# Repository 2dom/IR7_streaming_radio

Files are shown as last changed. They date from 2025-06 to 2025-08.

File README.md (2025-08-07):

<p style="color: #87CEEB"> DISCLAIMER: THE DESIGN FILES IN THIS REPOSITORY HAVE BEEN CLEARED OF ANY TRADEMARK-PROTECTED LOGOS.</p>

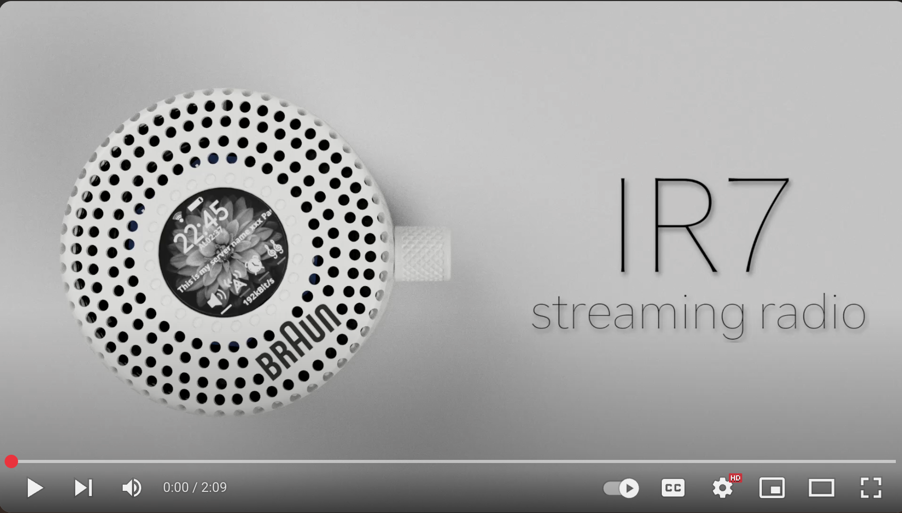
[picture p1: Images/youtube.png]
<p align="center"></p>

<h1>Less, but better</h1>
Legendary German industrial designer Dieter Rams is best known for his tenure at Braun, where he developed a design philosophy that emphasized simplicity, functionality, and clarity. His work was guided by the principle "Less, but better" (“Weniger, aber besser”), aiming to strip objects down to their essential purpose without unnecessary embellishment. Rams believed that good design is as little design as possible, and this ethos permeated his creations at Braun. His iconic "Ten Principles of Good Design" laid a foundation not only for Braun's product identity but also for the evolution of modern design aesthetics in consumer electronics globally.<br>
<br><br>
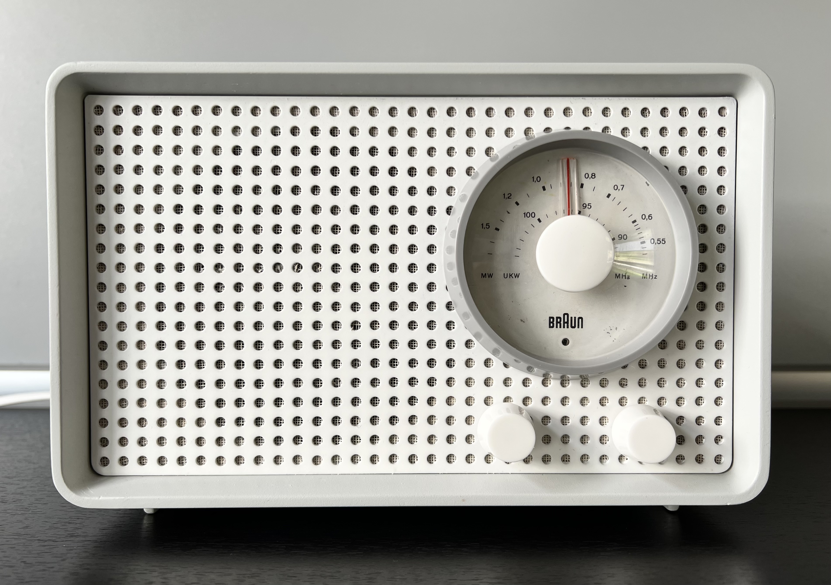
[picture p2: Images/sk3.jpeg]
<p align="center"><br>
Braun SK2 radio</p><br>
Among Rams' most influential designs are the SK2 radio, the TP1, and the T3 Pocket Radio. The SK2, introduced in 1955, featured a minimal white casing with a clear, intuitive layout, embodying the clarity and honesty Rams championed. The TP1 combined a record player and radio into one compact, portable device—a groundbreaking integration at the time—highlighting Rams’ commitment to multifunctional utility and user-friendly design. The T3 Pocket Radio, released in 1958, took these values even further: it was compact, elegant, and remarkably prescient, widely regarded as a spiritual predecessor to the Apple iPod due to its minimalist front face and clear functional layout.<br>
<br>
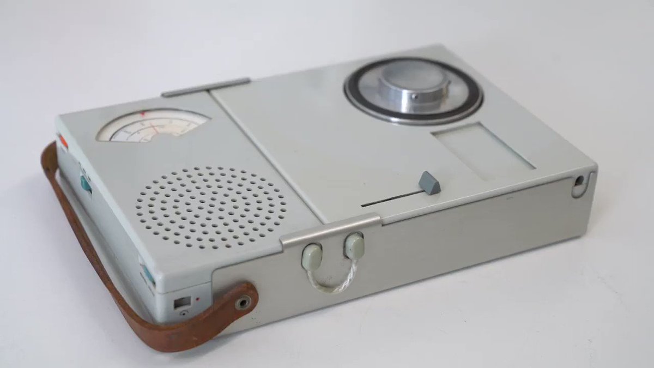
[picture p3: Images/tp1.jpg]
<p align="center"><br>
Braun TP1 portable record player</p><br>
Rams' influence on the design industry, particularly on companies like Apple, is unmistakable. Jony Ive, Apple’s former chief design officer, openly credited Rams as a major inspiration for the look and feel of Apple products. The restrained elegance and user-centric functionality of Braun devices under Rams’ direction clearly echo in Apple’s hardware—from the clean lines of the iPhone to the intuitive control layout of the iPod. Through designs like the SK2, TP1, and T3, Rams didn't just shape Braun’s identity; he helped define what good design means in the modern world, leaving a legacy that continues to shape the aesthetics and usability of consumer technology today.<br>
<br>
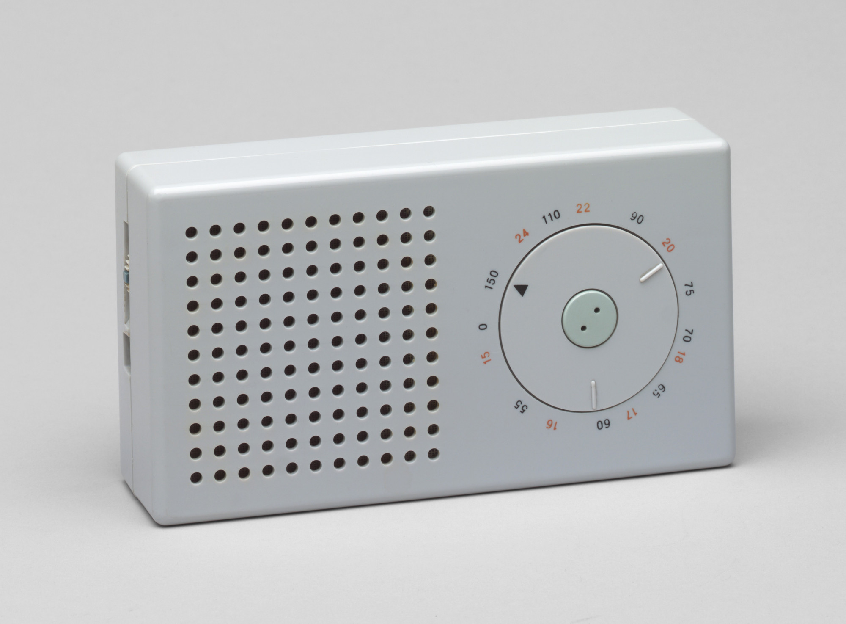
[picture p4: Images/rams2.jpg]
<p align="center"><br>
 Braun T3 portable radio</p>
<br>
After a glorious period of minimalist designwork, Dieter Rams' left Braun in the mid-1990s and the company gradually shifted away from its legacy of minimalist consumer electronics toward high quality personal care products, such as electric shavers, hair dryers, and epilators. <br>
<br>
Dieter Rams' design legacy lives on in many contemporary products, such as the portable recorders and synthesizers by Teenage Engineering.<br><br>
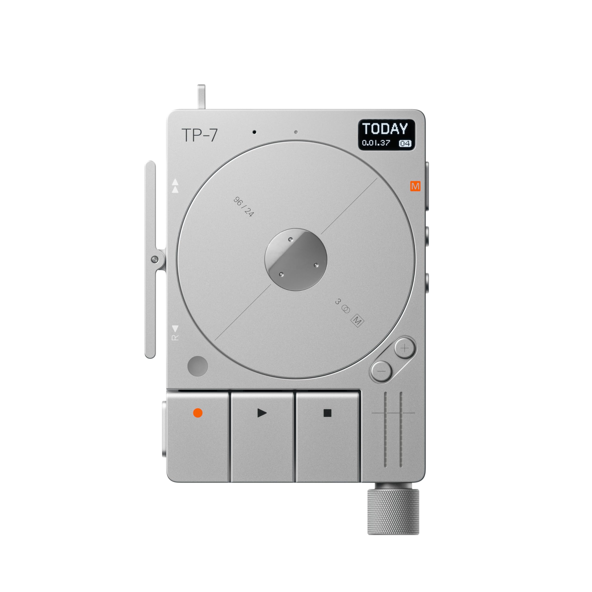
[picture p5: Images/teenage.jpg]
<p align="center"><br>
Teenage Engineering TP-7</p>

<h1>Something new</h1>
<p>Inspired by Braun’s iconic designs, particularly the T3, I started from the familiar speaker hole pattern and gradualy added elements that worked visually and physically (would fit the electronics). The first attempt was a direct copy of the T3 with an added square display (much like the iPod). Albeit the design worked reasonably well, it also felt overused and a lost opportunity in creating something new.<br>
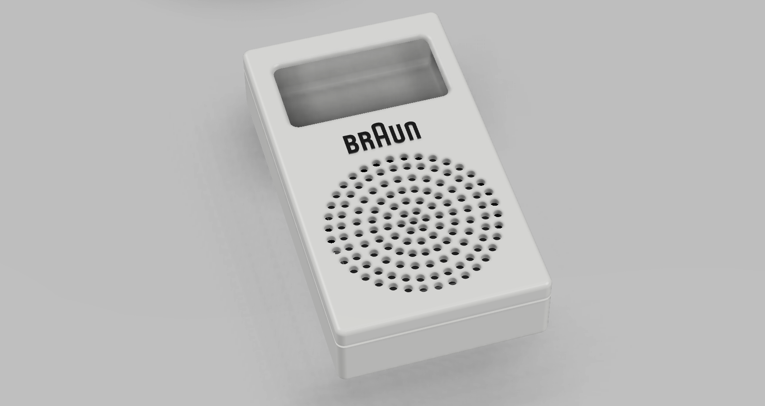
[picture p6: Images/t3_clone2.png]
 <p align="center"><br>
First concept based on T3 shape and TP1 hole pattern</p>
I kept experimenting with different shapes until a cylindrical form emerged, driven by the original hole pattern and the dimensions of the speaker. The top section simply extends the pattern into the 3rd dimensions, effectively serving as a 360 degree speaker grill. To complete the design, I also added the distinctive top/bottom gap reminiscent of the classic T3 that ties everything together.</p>
<p>Initially, I opted for a rectangular ultra–low-power monochrome display to maximize battery life. However, I soon realized that a) it looks rather hacked together b) such displays lack backlighting, making them practically unusable in an alarm clock / low-light kind of situation. So might as well use nice a round IPS LCD and turn it off during sleep. Not only does it complement the circular design of the case far more naturally, but it also offers a significantly better user experience thanks to its higher resolution and contrast.</p>
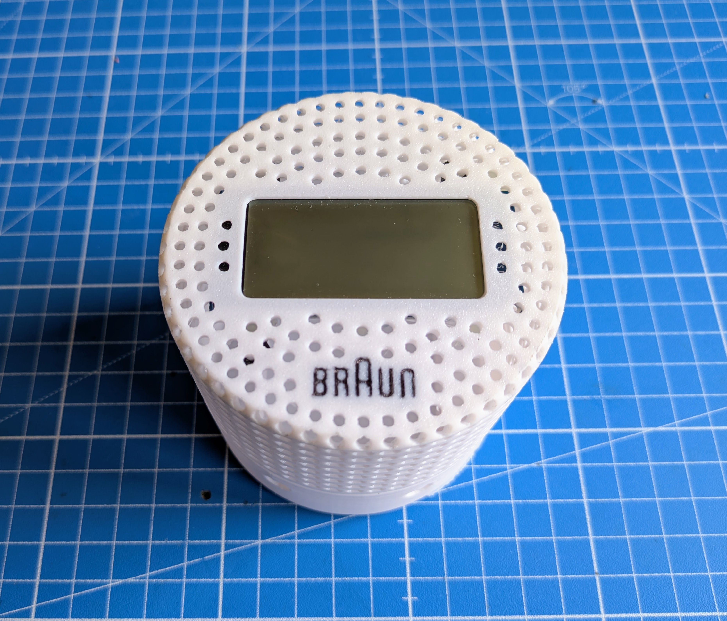
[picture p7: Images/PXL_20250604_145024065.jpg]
<p align="center"><br>
Rectangular ultra-low-power display</p>
<p>So how do we operate this thing? Although the GC9A01 also comes in a "touch" variant, I decided that a physical interface would work better for this build. I started off with two encoder knobs (one for station, one for volume), but reduced it later to a single knob angled at 45-degrees. This choice aligned much better with rest of the design and effectively simplified the user interface.<br>
 <br>Battery life is reasonably good too. The radio has a current consumption of about 800uA during sleep and 200mA during radio operation which equates to 220 days of standy or 22h of radio play using two 2200mAh 18650 cells. If you use it as a alarm clock, that's about 1.5 months of battery life, given that you need 30min to get out of bed each morning.</p>
<br>
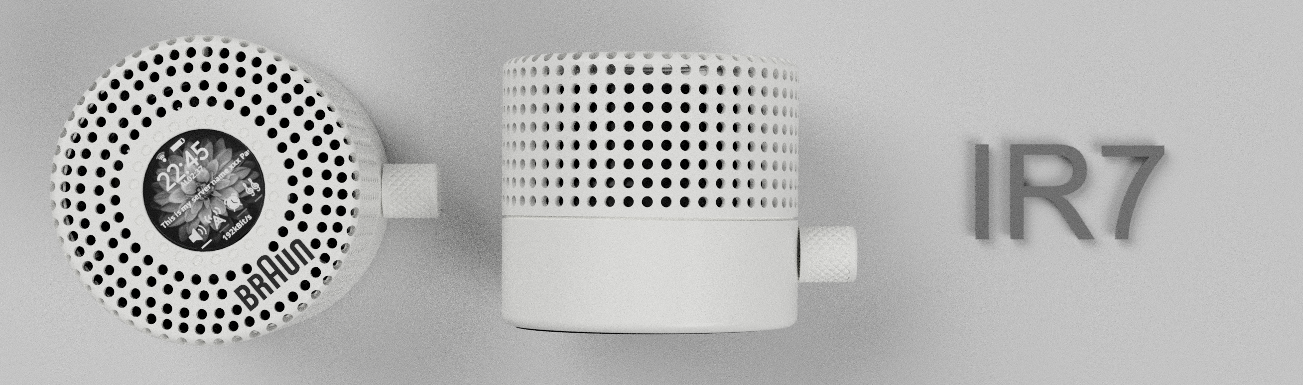
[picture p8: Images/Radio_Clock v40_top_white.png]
<p align="center"><br>
Final design</p>

<h1>Build Overview</h1>
 <p style="text-align:center;">The IR7 is built around a few key components:</p>
 
<table align="center">
<tr><th>Part list</th></tr>
<tr><td>Lolin32 Lite / ESP32 microcontroller with onboard battery charging- 3.80€</td></tr>
<tr><td>GC9A01 round IPS LCD display - 3.60€</td></tr>
<tr><td>DS3231 real-time clock - 1.10€</td></tr>
<tr><td>One or two 18650 batteries - 2.00€</td></tr>
<tr><td>VS1053 MP3 decoder board - 5.20€</td></tr>
<tr><td>PAM8403 audio amplifier - 0.40€</td></tr>
<tr><td>600:600 Ohm isolation transformer for cleaner audio - 0.50€</td></tr>
<tr><td>2–2.5 inch wideband speaker (e.g., Visaton FR7) - 7.00€</td></tr>
<tr><td>Rotary encoder - 0.20€</td></tr>
<tr><td>TS3134 P-Channel MOSFET - 0.10€</td></tr>
<tr><td>Miscellaneous resistors and plastic screws - 0.10€</td></tr>
<tr><td>3D printed parts (optionally from JLCPCB) - 2.00€ (15.00€)</td></tr>
<tr><td><b>TOTAL - 27.00€ (40.00€)</b></td></tr>

</table>
<br>
First, let’s get started by preparing the 3D-printed components. You can either print the four plastic parts yourself — the lower shell, upper shell, resonator, and knob — or order them from a 3D printing service of your choice.<br>
<br>
While my FDM printer handled the case fairly well, it struggled with producing perfectly round vertical holes — a common limitation of that printing method. To get the best quality, I chose to have the parts SLA-printed by JLCPCB, and the results were excellent.<br>
<br>
<p align="center">
  <br>
<br>
Plastic parts</p>
<br>
Begin by gluing the ESP32 board and rotary encoder into their designated locations. Avoid using thermoplastic (e.g. hot) glue, as the microcontroller can heat up significantly during charging and will delaminate.<br><br>
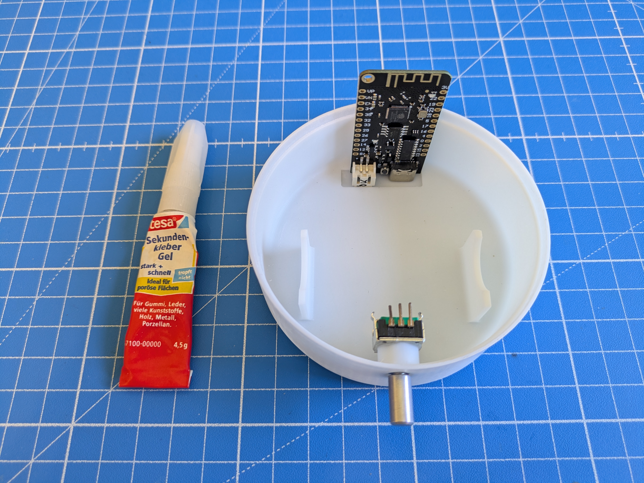
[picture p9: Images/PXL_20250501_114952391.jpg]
<p align="center"><br>
Step 1 - ESP32 & encoder</p>
Next, insert the speaker into the resonator tube. I’ve included cutout sizes for both 2-inch and 2.5-inch speakers. Use plastic screws to secure the speaker. If the fit is tight, you may need to carefully trim the edges. Finally, solder the speaker wires to the terminals.<br>
<br>
<p align="center"><br>
  <br>
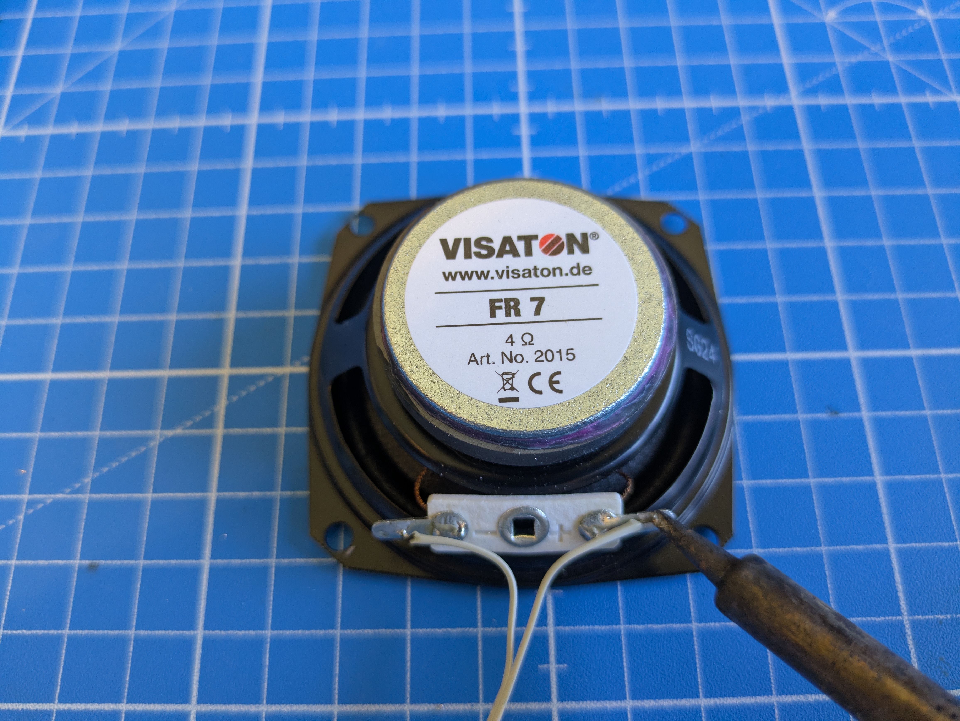
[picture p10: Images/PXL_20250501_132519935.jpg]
<br>
  <br>
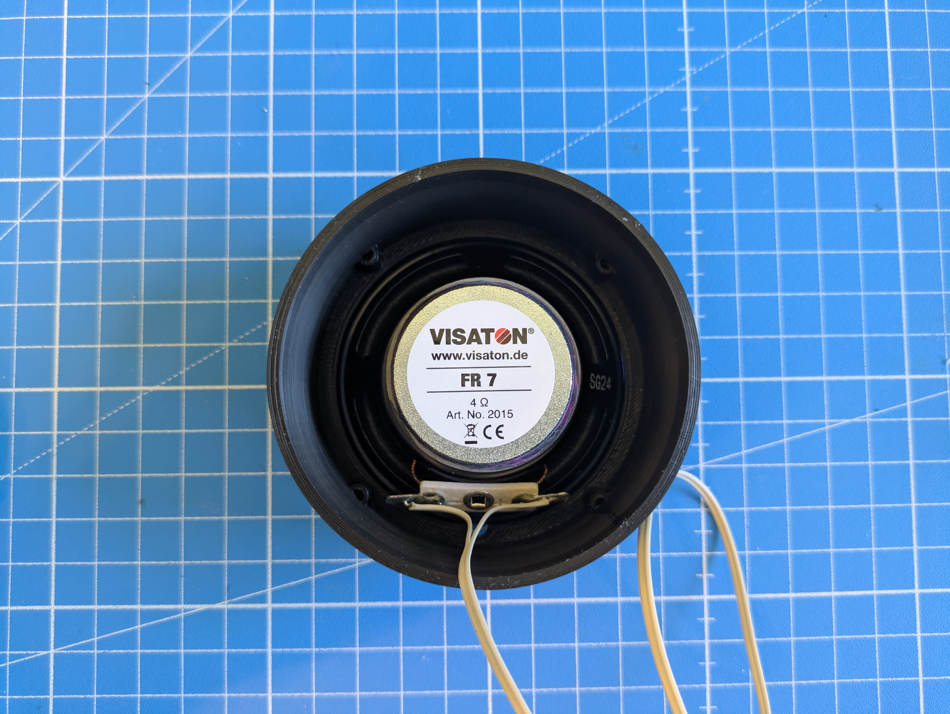
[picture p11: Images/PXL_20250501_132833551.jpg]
<br>
Step 2 - Speaker</p>
Since the VS1053/VS1003 audio output is only suitable to drive headphones, an audio amplifier is needed. However, directly connecting the amplifier to the VS1053 introduces noticeable noise. The solution: use an audio isolation transformer. I soldered mine directly onto the amplifier board to keep the design compact and reduce cable length, which minimizes noise pickup. Connect the amplifier and transformer to the VS1053 using two 1kΩ resistors. Note that you want to use a geeen VS1053 board commonly available on Ebay and Aliexpress. The blue board shown in the picture actually uses an VS1003 chip which is somewhat compatible but supports less codecs and has a few other quirks.<br>
<br>
<p align="center"><br>
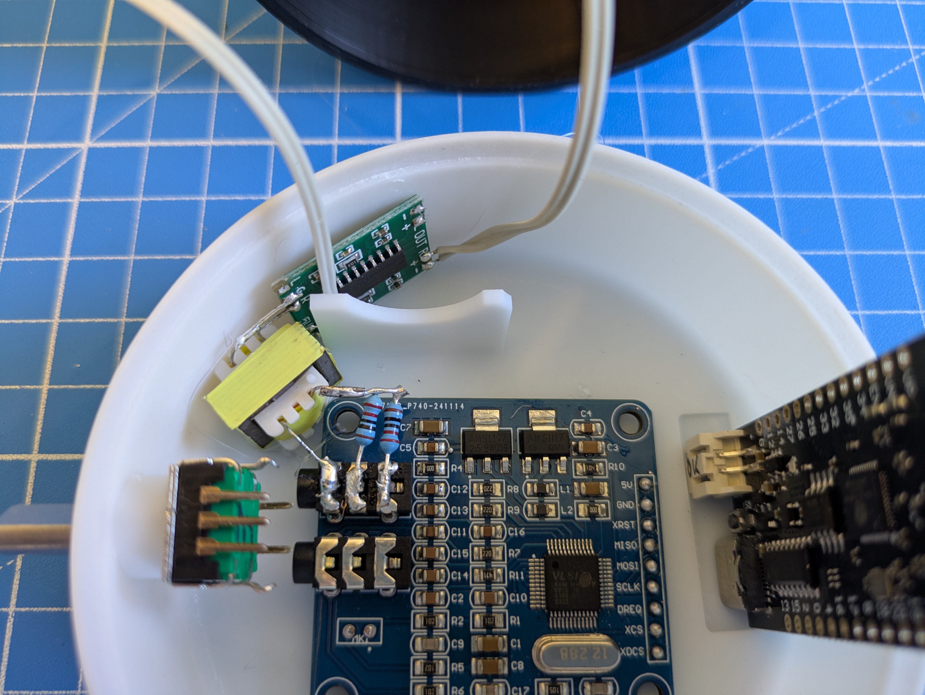
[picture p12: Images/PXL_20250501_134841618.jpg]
<br>
Step 3 - Audio</p>
Solder thin signal wires to all exposed pins on the LCD display board. Insert the display into the upper shell and secure it with glue (hot glue works fine here). Feed the signal wires through the small hole in the resonator, then slide the speaker-resonator assembly into the upper shell and secure it in place with some glue. Finally, connect the signal wires and VCC to the ESP32.<br>
<br>
<p align="center"><br>
<br>
Step 4 - Display</p>
Even though most components (except the amp) support low-power modes, I found that the sleep current still hovers around 1.5 mA. To truly optimize battery life, a TS3134 MOSFET is used to cut power to all peripherals during sleep. Connect it between battery ground and the ground lines for the display, VS1053, and amplifier. <br>
<br>
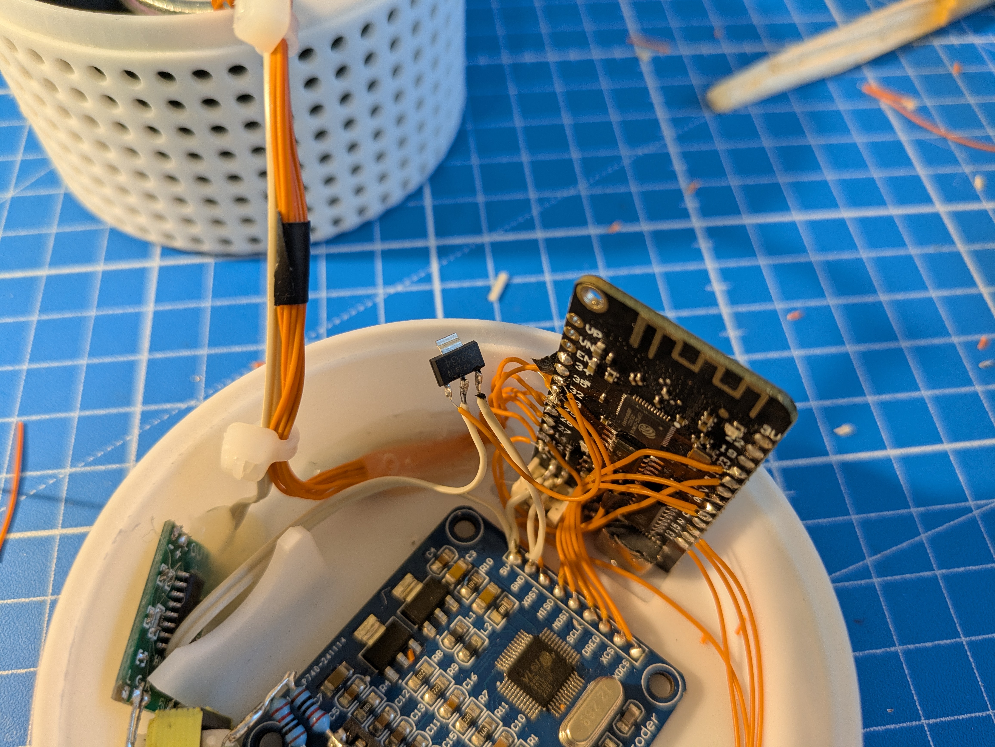
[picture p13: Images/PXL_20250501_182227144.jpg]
<p align="center"><br>
Step 5 - Low power</p>
Solder two power wires to the battery terminals. To monitor battery voltage add a voltage divider made of two 10kΩ resistors to bring the voltage down to a safe 0–2.2V range for the ESP32.
<br>
<br> 
<p align="center"><br>
 Step 6 - Battery</p>
 <br>
The ESP32's built-in RTC is notoriously unreliable. To ensure accurate timekeeping and enable timed wake-ups, we use a DS3231 Real-Time Clock module. It keeps time while the system is asleep and can trigger an interrupt to wake the ESP32 at a precise time. On some modules, the interrupt pin isn’t exposed — in that case, you’ll need to solder a wire directly to the chip (see picture).
<p align="center">
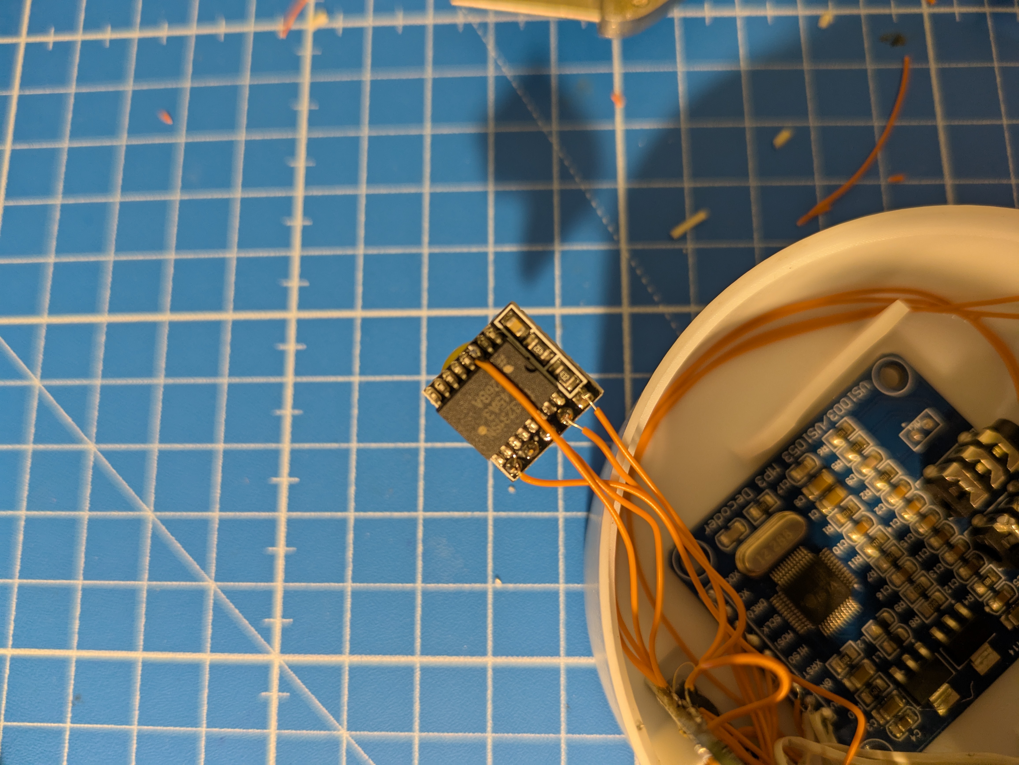
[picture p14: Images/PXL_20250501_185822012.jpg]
  <p align="center"> <br>
 Step 7 - Real Time Clock</p>
The final component to wire up is the rotary encoder. After connecting all GPIO and power wires, secure any loose parts — including the RTC, battery, MOSFET, etc. — with glue to keep everything neat and stable inside the case.<br>
<br>
<table align="center">
    <tr><th>GPIO map</th></tr>
    <tr><td>SPI_MISO_PIN GPIO_NUM_12</td></tr>
    <tr><td>SPI_MOSI_PIN GPIO_NUM_25</td></tr>
    <tr><td>SPI_CLK_PIN GPIO_NUM_33</td></tr>
    <tr><td>VS1053_DREQ GPIO_NUM_23</td></tr>
    <tr><td>VS1053_CS GPIO_NUM_17</td></tr>
    <tr><td>VS1053_DCS GPIO_NUM_16</td></tr>
    <tr><td>VS1053_RST GPIO_NUM_18</td></tr>
    <tr><td>LCD_DC GPIO_NUM_26</td></tr>
    <tr><td>LCD_CS GPIO_NUM_27</td></tr>
    <tr><td>LCD_BL GPIO_NUM_4</td></tr>
    <tr><td>MOSFET_EN GPIO_NUM_32</td></tr>
    <tr><td>ENC1_BUT GPIO_NUM_13</td></tr>
    <tr><td>ENC1_A GPIO_NUM_15</td></tr>
    <tr><td>ENC1_B GPIO_NUM_2</td></tr>
    <tr><td>DS3231_CLK GPIO_NUM_0</td></tr>
    <tr><td>DS3231_SDA GPIO_NUM_5</td></tr>
    <tr><td>VCC_PIN 34</td></tr>
 </table>
<br>
<p align="center"><br>
 Step 8 - Encoder wiring and finishing touches</p>
<br>
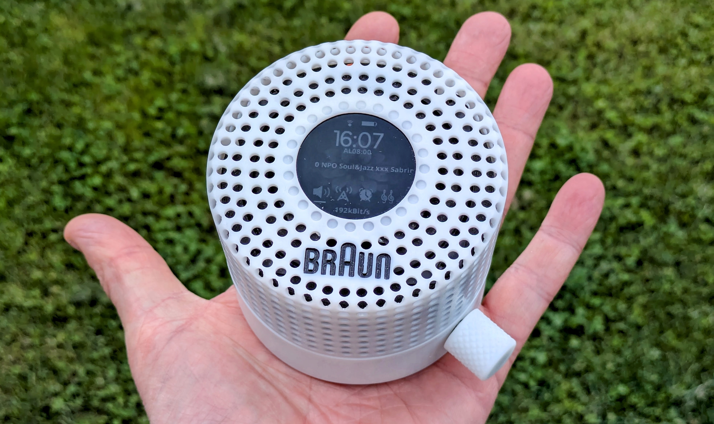
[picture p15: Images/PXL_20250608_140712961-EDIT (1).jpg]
<p align="center"><br></p><br> 

<h1>Uploading the Software to the ESP32</h1>

Once your hardware is assembled, it’s time to upload the firmware and web assets to the ESP32. You can use either the **Arduino IDE** or **PlatformIO**. Both work—choose whichever you're more comfortable with.

---

### 🧰 Arduino IDE

1. **Install Required Boards and Libraries**
   - Install the **ESP32 by Espressif Systems** board via the **Boards Manager**.
   - Use the **Library Manager** to install:
     - `TFT_eSPI`
     - `VS1053_ext` (from this repo or local import)
     - `AiEsp32RotaryEncoder`
     - `RTClib`
     - `ESP32Time`

2. **Select Your Board**
   - Go to `Tools > Board` and choose your ESP32 model (e.g., **ESP32 Dev Module**).

3. **Configure TFT_eSPI**
   - The IR7 uses a **GC9A01 240x240 round display**.  
     Replace the contents of `TFT_eSPI/User_Setup.h` with:
     ```cpp
     #define GC9A01_DRIVER

     #define TFT_WIDTH  240
     #define TFT_HEIGHT 240

     #define TFT_CS   27  // Chip select
     #define TFT_DC   26  // Data/command
     #define TFT_RST  -1  // Reset pin (set to -1 if not used)

     #define TFT_SCLK 33
     #define TFT_MOSI 25

     #define LOAD_GLCD
     #define LOAD_FONT2
     #define LOAD_FONT4
     #define LOAD_FONT6
     #define LOAD_FONT7
     #define LOAD_FONT8

     #define SMOOTH_FONT

     #define SPI_FREQUENCY  40000000
     ```
   - Alternatively, use the `User_Setup.h` file provided in the `lib/TFT_eSPI/` folder of this repo.

4. **Upload the Code**
   - Open `main.ino`, select the correct port, and click **Upload**.

5. **Upload SPIFFS Data (Stations & Wi-Fi)**
   - Install the [ESP32 Sketch Data Upload tool](https://github.com/me-no-dev/arduino-esp32fs-plugin).
   - Place `stations.txt` and `wifi.txt` inside a folder named `data/`.
   - Then go to **Tools > ESP32 Sketch Data Upload** to flash the SPIFFS filesystem.

---

### 🧰 PlatformIO (VS Code)

1. **Open the Project**
   - Use **VS Code** with the **PlatformIO** extension and open the IR7 project folder.

2. **Dependencies**
   - These libraries are automatically handled via `platformio.ini`, but ensure these are present:
     - `TFT_eSPI`
     - `VS1053_ext`
     - `AiEsp32RotaryEncoder`
     - `RTClib`
     - `ESP32Time`

3. **Configure TFT_eSPI**
   - Place the same `User_Setup.h` as shown above into `lib/TFT_eSPI/` or override it using `platformio.ini`:
     ```ini
     build_flags =
       -DUSER_SETUP_LOADED=1
       -include src/User_Setup.h
     ```
   - Then place the `User_Setup.h` file into the `src/` directory.

4. **Upload Firmware**
   ```bash
   pio run --target upload

<h1>Device Setup: Wi-Fi & Station Configuration</h1>

### Entering Setup Mode (Configuration/AP Mode)

To configure Wi-Fi and radio stations, you need to enter **setup mode** (also called AP mode):

1. **Hold the Encoder Button**  
   - While powering up (or rebooting) the device, **press and hold the rotary encoder button**.  
   - Keep holding until the screen displays “Braun IR7 Config” and “Connect to Wifi:” (the device will now act as a Wi-Fi Access Point).

2. **Connect to the Device’s Wi-Fi**  
   - On your phone, tablet, or computer, search for the Wi-Fi network named:  
     **Braun IR7 Config**  
   - Connect to this network (no password required).

3. **Access the Web Interface**  
   - Open a web browser and go to:  
     **http://192.168.4.1**  
     *(You’ll be automatically redirected if you try any URL.)*

### Entering Wi-Fi and Password Information

- On the configuration page, you’ll see a field labeled:
  **Wi-Fi Credentials (SSID;password per line)**
- Enter your Wi-Fi credentials in this format:  
your_wifi_ssid;your_wifi_password another_ssid;another_password

Code
*(Each line corresponds to one network. You can add multiple networks if desired.)*

### Adding, Removing, or Editing Radio Stations

- Below the Wi-Fi section, there’s a field labeled:
**Radio Stations (name@url per line)**
- Enter your favorite streaming radio stations in this format:
Radio Paradise@http://stream.radioparadise.com/mp3-128 BBC World@http://bbcmedia.ic.llnwd.net/stream/bbcmedia_radio1_mf_p

Code
*(Each line should have a station name, then an `@`, then the stream URL.)*

- **To add a station:**  
Just add a new line.
- **To edit/remove a station:**  
Modify or delete the relevant line.

### Save & Reboot

- Once you’ve entered your Wi-Fi and station details, **click “Save & Reboot”**.
- The device will store your settings, reboot, and attempt to connect to the Wi-Fi network(s) you’ve provided.
- After setup, the device will start streaming from your list of stations.

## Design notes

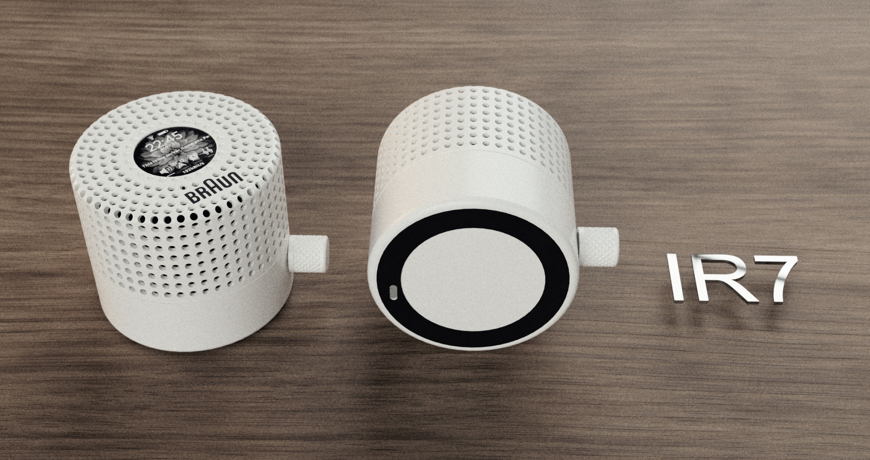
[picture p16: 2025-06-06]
Images/Radio_Clock v39.jpg

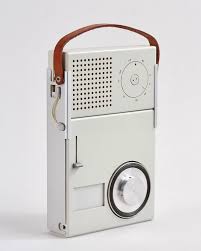
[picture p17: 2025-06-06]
Images/rams1.jpeg

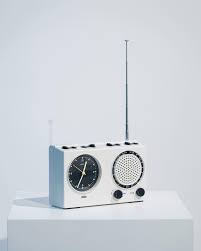
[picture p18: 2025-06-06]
Images/rams3.jpeg

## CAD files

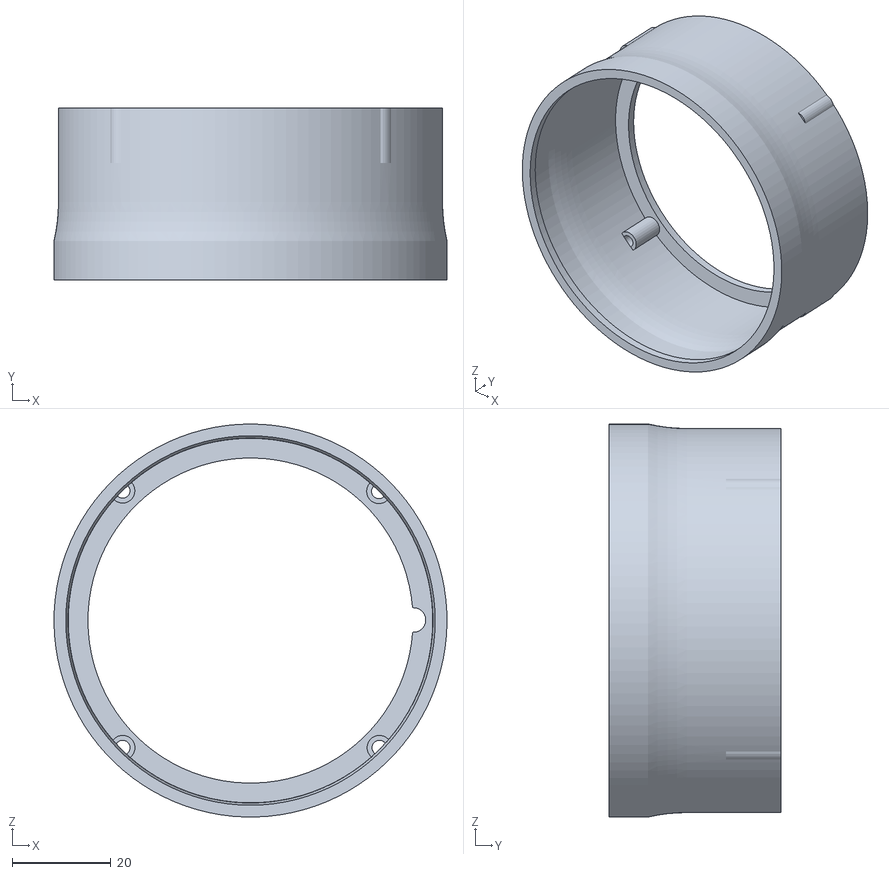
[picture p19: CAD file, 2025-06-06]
Hardware/Resonator_large.stl
79.8 x 35.0 x 79.8

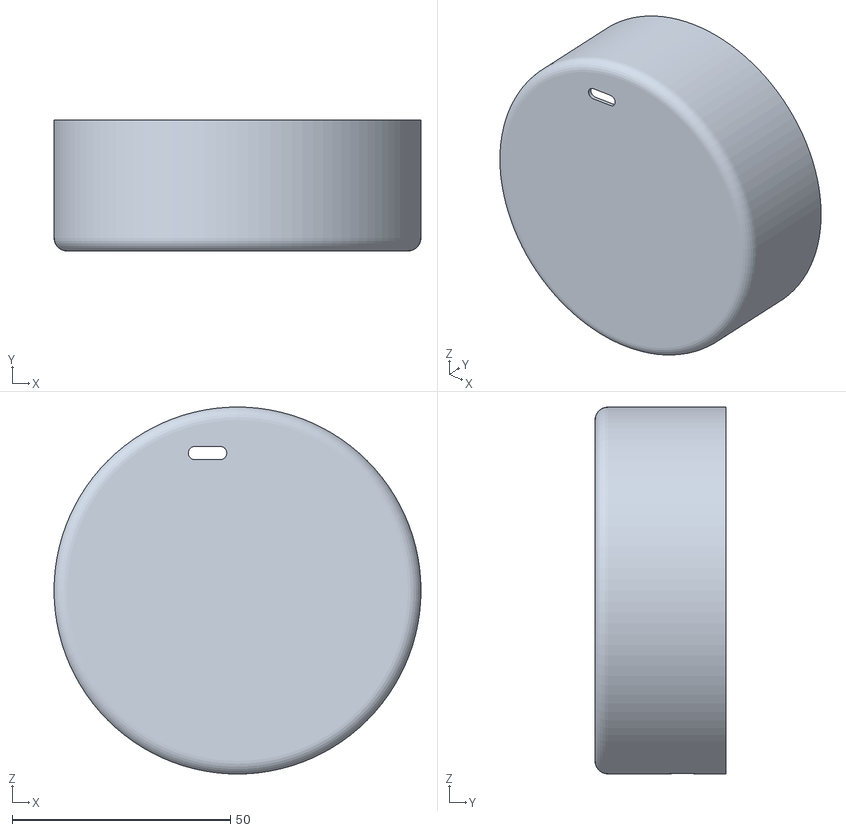
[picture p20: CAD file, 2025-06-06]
Hardware/Bottom_clean.stl
84.0 x 30.0 x 84.0

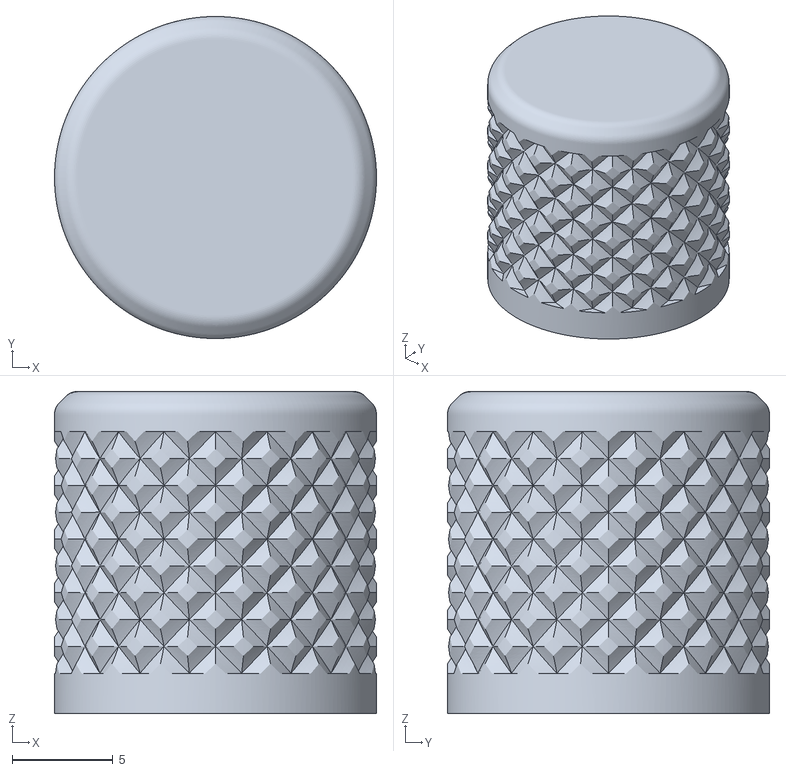
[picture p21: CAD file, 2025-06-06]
Hardware/Knob_clean.stl
16.0 x 16.0 x 16.0

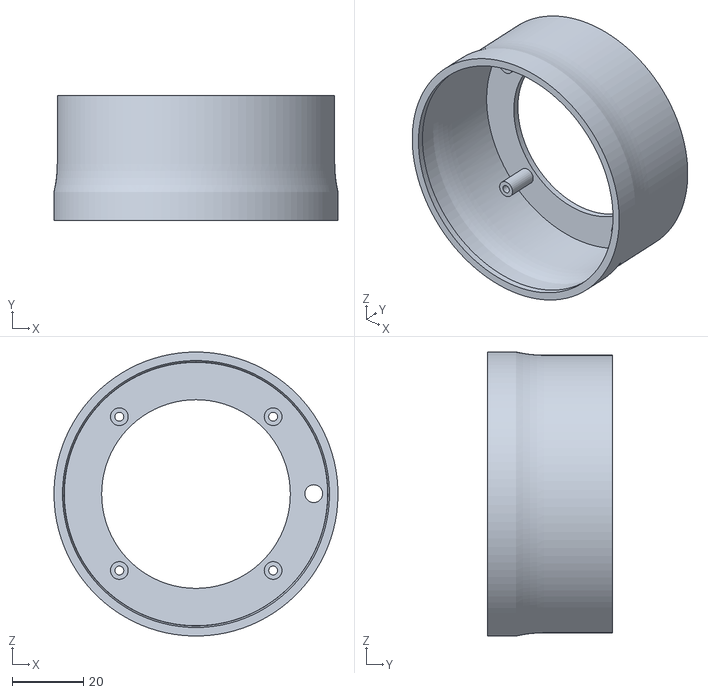
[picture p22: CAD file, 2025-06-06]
Hardware/Resonator_small.stl
79.8 x 35.0 x 79.8

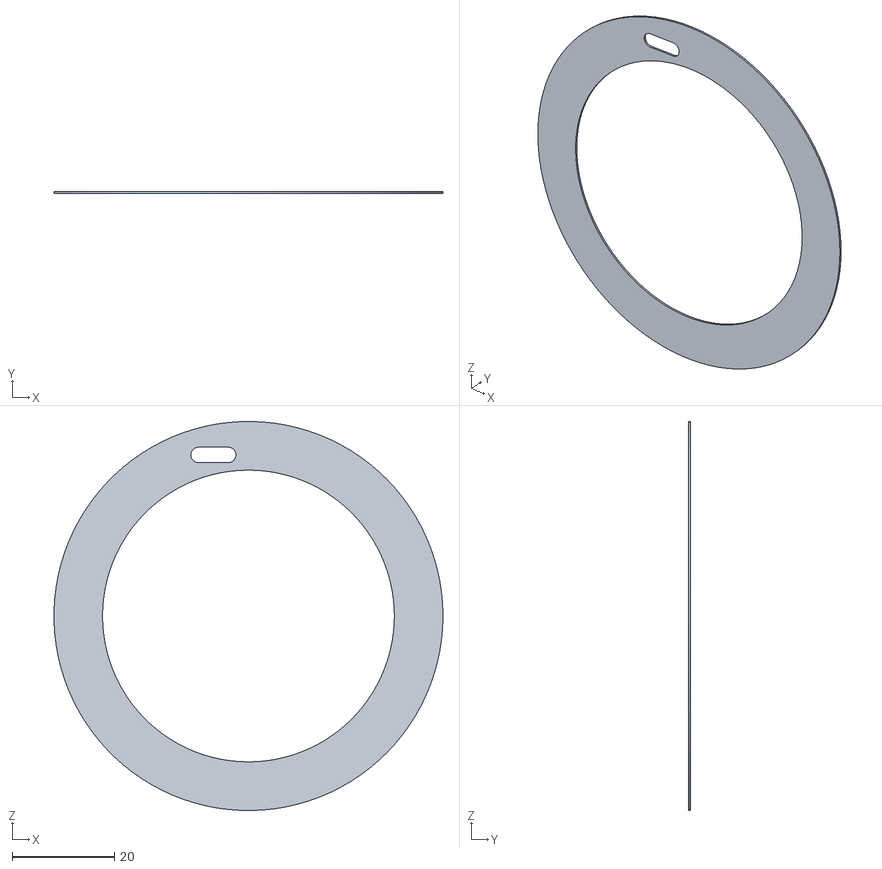
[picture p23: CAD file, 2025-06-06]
Hardware/Coaster_clean.stl
76.0 x 0.4 x 76.0

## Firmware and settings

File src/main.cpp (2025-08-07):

/*********************************************************************
Braun IR7 Web Radio & Alarm Clock Firmware

This firmware turns an ESP32-based device into a fully featured web radio and alarm clock with the following features:
  - Streams internet radio stations using a VS1053 audio decoder.
  - WiFi configuration and radio station management via a built-in web interface (AP mode).
  - Rotary encoder for intuitive control of volume, station, alarm time, and tone settings.
  - Color TFT display for time, menus, battery, WiFi status, and scrolling song/station info.
  - Real-time clock (RTC) with NTP synchronization and alarm functionality.
  - Battery voltage monitoring and automatic sleep for power saving.
  - Designed for the Braun IR7 hardware, but adaptable to similar ESP32 + VS1053 + TFT projects.

Written by Dominic Buchstaller.
BSD license, check license.txt for more information
*********************************************************************/


#include <Arduino.h>
#include <WiFi.h>
#include <WiFiMulti.h>
#include <WiFiUdp.h>
#include <WiFiClient.h>
#include <WebServer.h>
#include <DNSServer.h>
#include <SPIFFS.h>
#include <Preferences.h>
#include <esp_task_wdt.h>
#include <VS1053_ext.h>              
#include "images.h"
#include "AiEsp32RotaryEncoder.h"
#include "driver/rtc_io.h"
#include <TFT_eSPI.h>
#include <ESP32Time.h>
#include "time.h"
#include "NotoSansBold15.h"
#include "Agnella-Bold50.h"
#include "Agnella-Bold30.h"
#include "RTClib.h"
#include "esp_sntp.h"

WiFiMulti wifiMulti;

// Select one backround image
//#define BACKROUND BACKROUND0   // Hex pattern backround
#define BACKROUND BACKROUND1   // Flower backround
//#define BACKROUND BACKROUND2   // Minimal backround


// Select one vendor logo
//#define VENDOR_LOGO VENDOR_LOGO0   // AI generated backround
#define VENDOR_LOGO VENDOR_LOGO1   // Braun backround

// Select one menu
#define MENU MENU0   // AI generated backround
//#define VENDOR_LOGO VENDOR_LOGO1   // Braun backround

#define SPI_MISO_PIN GPIO_NUM_12
#define SPI_MOSI_PIN GPIO_NUM_25
#define SPI_CLK_PIN GPIO_NUM_33
#define VS1053_DREQ GPIO_NUM_23
#define VS1053_CS GPIO_NUM_17
#define VS1053_DCS GPIO_NUM_16
#define VS1053_RST GPIO_NUM_18
#define LCD_DC GPIO_NUM_26
#define LCD_CS GPIO_NUM_27
#define LCD_BL GPIO_NUM_4
#define VCC_PIN 34
#define MOSFET_EN GPIO_NUM_32
#define ENC1_BUT GPIO_NUM_13
#define ENC1_A GPIO_NUM_15
#define ENC1_B GPIO_NUM_2
#define ENC1_STEPS 5
#define DS3231_CLK GPIO_NUM_0
#define DS3231_SDA GPIO_NUM_5

#define myabs(x) ((x)>0?(x):-(x))

WebServer server(80);
bool ap_mode = false;

const byte DNS_PORT = 53;
DNSServer dnsServer;

// Time keeping
#define uS_TO_SEC_FACTOR 1000000ULL
RTC_DS3231 rtc;

// This semapohore manages the SPI bus between LCD and MP3 board
// In theory this should work without but it is much more stable this way
SemaphoreHandle_t SPIsem = NULL;  

// This struct holds the configuration for volume, station, alarm and bass
#define num_configs 4
uint8_t active_config;
struct config_struct
{
  long high_limit=0;
  long low_limit=0;
  long value=0;
};

RTC_DATA_ATTR config_struct myconfig[num_configs];
RTC_DATA_ATTR bool alarm_on;
#define CONFIG_SIZE sizeof(myconfig)

// This is the y value on the LCD where the single title and station is displayed
int title_pos=115;

unsigned long last_second_update=0; // This is used executing one second repeating tasks
unsigned long last_user_activity=0; // Last time the user did something
unsigned long auto_sleep_timeout=30*60*1000; // Radio goes to sleep after x ms after wakeup from alarm
bool auto_sleep=false;
int last_rssi_update=0; // Last Wifi signal strength
int rssi_limits[]={-80,-70,-67,-50,-30}; // This defines the quality of the wifi signal in five steps (from bad to good)
float last_vcc; // Last battery voltage
int last_minute_update=255; // Last minute of the current time
unsigned long last_station_change=0; // Last time the station was changed
bool change_station=false;  // The station has been changed

// // NTP stuff
String timezone = "CET-1CEST,M3.5.0,M10.5.0/3"; // Berlin
const char* ntp_server = "192.53.103.108"; // ptbtime1.ptb.de Braunschweig

// Wifi stuff
const char* SSID[] = {};//"Look mum...no wires!","FRITZ!BoxGastzugang"};
const char* PSK[] = {};//"huibuhdasnachtgespenst","diefischerinvombodensee"};
#define no_wifi_networks sizeof(SSID)/sizeof(SSID[0])
const uint32_t connectTimeoutMs = 3000;

bool sync_ntp_time=false; // Has NTP time been synced to external real time clock?

// Econder wheel - the last argument enables pull-up resistors for ENC1_A and ENC1_B
AiEsp32RotaryEncoder encoder1 = AiEsp32RotaryEncoder(ENC1_B, ENC1_A, -1, -1, ENC1_STEPS,0); 

// 2nd core task for handling wifi and MP3 stuff
TaskHandle_t Task0;

// Scrolling station name and text
unsigned long last_text_move=0; // Last time the text moved 
int display_text_len;
int display_text_pos;
String station_text, song_text, display_text;

// Display stuff - sprites for scrolling text and displaying current time
TFT_eSPI display = TFT_eSPI();
TFT_eSprite ScrollTextSprite = TFT_eSprite(&display); 
TFT_eSprite ClockSprite = TFT_eSprite(&display);
#define TFT_MY_GRAY 0x3186

// Position of graphical elements
int battery_y_pos=15;
int battery_x_pos=140;
int wifi_y_pos=25;
int wifi_x_pos=100;
int menu_y_pos=165;

String this_stream_url;
String this_stream_name;

VS1053 mp3(VS1053_CS, VS1053_DCS, VS1053_DREQ, VSPI, SPI_MOSI_PIN, SPI_MISO_PIN, SPI_CLK_PIN);


unsigned long start_time;

// NTP Sync successful
void timeSyncCallback(struct timeval *tv)
{
  sync_ntp_time=true;
}

// Encoder interrupt
void IRAM_ATTR readEncoderISR1()
{
  encoder1.readEncoder_ISR();
}

// Fade pins in and out
void pin_fade(bool in, gpio_num_t pin, uint8_t delay_value = 5)
{
   if (in)
   {
    for (int bright=0; bright<255; bright++)
    {
      analogWrite(pin,bright);
      delay(delay_value);
    }
   }
   else
   {
    for (int bright=255; bright>0; bright--)
    {
      analogWrite(pin,bright);
      delay(delay_value);
    }
   }
}

// Nap time
void got_to_sleep()
{
  pin_fade(0,LCD_BL);
  display.fillScreen(TFT_BLACK);
  display.writecommand(0x10); // Turn display off / power saving mode
  digitalWrite(LCD_BL,LOW);

  // Fade out volume
  for (int i=myconfig[0].value; i>0; i--)
  {
    mp3.setVolume(i);
    delay(10);
  }

  digitalWrite(MOSFET_EN,LOW); // Amp off
  pinMode(VS1053_RST,INPUT); // This will put the device in low power mode (on-board pullup for RST)
  esp_sleep_enable_ext0_wakeup(ENC1_BUT, LOW); 
  
  // Hold levels during sleep
  gpio_deep_sleep_hold_en();
  gpio_hold_en(MOSFET_EN);
  

  while (digitalRead(ENC1_BUT)==LOW)
    delay(10);

  // Set alarm clock
  if (alarm_on)
  {
    DateTime now = rtc.now();
    int hour = now.hour();
    int minute = now.minute();  
    Serial.println("RTC local time at sleep: " + String(hour) + ":" + String(minute));
    
    rtc.disableAlarm(1);
    rtc.clearAlarm(1);
    rtc.disableAlarm(2);
    rtc.clearAlarm(2);
    int alarm_hour = myconfig[2].value/60;
    int alarm_minute = myconfig[2].value%60;
    // We set the alarm for 20 secs before the alarm time to account for boot-up
    DateTime alarm_time;
    alarm_time  = DateTime(2020, 6, 25, alarm_hour, alarm_minute, 0) - TimeSpan(0, 0, 0, 20);
    rtc.setAlarm1(alarm_time, DS3231_A1_Hour);
    Serial.println("Alarm is set for "+ String (alarm_time.hour()) + ":" + String(alarm_time.minute()));
    
  }
  else
  {
    rtc.disableAlarm(1);
    rtc.clearAlarm(1);
    rtc.disableAlarm(2);
    rtc.clearAlarm(2);
  }
  delay(100);
  esp_deep_sleep_start(); // <--------------------------SLEEEEEP
}

// Draw the menu
void draw_menu()
{
  display.pushImage(35,menu_y_pos, MENU_WIDTH, MENU_HEIGHT, MENU, TFT_BLACK);
  int select_width=25;
  int select_y=205;
  for (int selector=0; selector<4; selector++ )

  {
    if (active_config==selector)
      display.fillRect(53+selector*46-select_width/2,select_y,select_width,3,TFT_WHITE);
    else
      display.fillRect(53+selector*46-select_width/2,select_y,select_width,3,0x4a69);
  }
}

// Draw wifi reception indicator
void draw_wifi()
{ 
  int sig_db = WiFi.RSSI();
  if (sig_db!= last_rssi_update)
  {
    last_rssi_update= sig_db;
    Serial.println("Wifi signal (db): " + String(sig_db));

    if (sig_db>rssi_limits[0])
      display.fillSmoothCircle(wifi_x_pos,wifi_y_pos,3,TFT_WHITE);
    else
      display.fillSmoothCircle(wifi_x_pos,wifi_y_pos,3,TFT_DARKGREY);
    for (int i=0; i<4; i++)
    {
      if (sig_db>rssi_limits[i+1])
        display.drawSmoothArc(wifi_x_pos,wifi_y_pos,6+3*i,7+3*i,140,220,TFT_WHITE,TFT_BLACK,true);
      else
        display.drawSmoothArc(wifi_x_pos,wifi_y_pos,6+3*i,7+3*i,140,220,TFT_DARKGREY,TFT_BLACK,true);
    }
  }
}

void bat_empty()
{
  display.pushImage(0,0,240,240,BAT_EMPTY_LOGO);
  delay(2000);
  got_to_sleep();
}

// Draw battery voltage indicator
void draw_battery()
{
  float current_vcc=analogRead(VCC_PIN)/565.0;
  if (current_vcc<3.2)
    bat_empty();
  float delta_vcc = abs(current_vcc-last_vcc);
  if (delta_vcc > 0.1)
  {
    Serial.println("VCC battery: " + String(current_vcc) + ", delta_vcc" + String(delta_vcc));
    last_vcc=current_vcc;
    int battery_width=30;
    int battery_height=10;
    int battery_knob_height=6;
    int battery_knob_width=2;
    
    display.fillRect(battery_x_pos-battery_width/2,battery_y_pos,battery_width,battery_height,TFT_BLACK);
    display.drawRect(battery_x_pos-battery_width/2,battery_y_pos,battery_width,battery_height,TFT_WHITE);
    display.fillRect(battery_x_pos+battery_width/2,battery_y_pos+battery_height/2-battery_knob_height/2,battery_knob_width,battery_knob_height,TFT_WHITE);
  
    if (current_vcc<3.2) current_vcc=3.2;
    if (current_vcc>4.2) current_vcc=4.2;
    
    float current_vcc_PC=(current_vcc-3.2); // between 0.0 and 1.0
    
    display.fillRect(battery_x_pos-battery_width/2+1,battery_y_pos+1,(int)((float)battery_width-2.0)*current_vcc_PC,battery_height-2,TFT_WHITE);
    
  }
}

// Draw alarm time
void draw_alarm()
{
  int hour = myconfig[2].value/60;
  int minute = myconfig[2].value%60;
  int alarm_y_pos=80;
  String time_string = "AL";
  if (hour<10) time_string+="0";
  time_string +=String(hour)+":";
  if (minute<10) time_string+="0";
  time_string +=String(minute);
  
  display.loadFont(NotoSansBold15);
  int time_string_len=display.textWidth(time_string);  
  display.setCursor(120-time_string_len/2, alarm_y_pos);
  if (alarm_on)
    display.setTextColor(TFT_RED, TFT_DARKGREY); 
  else  
    display.setTextColor(TFT_WHITE, TFT_DARKGREY);
  display.pushImage(0,alarm_y_pos,240,17,BACKROUND+240*alarm_y_pos);
  display.println(time_string);	
}

// Draws the current time
void draw_time()
{
  DateTime now = rtc.now();
  int hour = now.hour();
  int minute = now.minute();  

  if (minute!= last_minute_update)
  {
    String time_string;
    if (hour<10) time_string+="0";
    time_string +=String(hour)+":";
    if (minute<10) time_string+="0";
    time_string +=String(minute);

    Serial.println("Drawing time: " + time_string);
    
    int time_string_len=ClockSprite.textWidth(time_string);
    ClockSprite.setCursor(120-time_string_len/2, 0);
    ClockSprite.setTextColor(TFT_WHITE, TFT_DARKGREY); 
    ClockSprite.pushImage(0,0,240,40,BACKROUND+240*40);
    ClockSprite.println(time_string);	
    ClockSprite.pushSprite(0,40);
    display.drawSmoothArc(120,120,119,120,0,360,TFT_MY_GRAY,TFT_BLACK,false);
    
    last_minute_update=minute;
  }
  
}

// Start the mp3 decoder board
void start_VS1003 (){
  Serial.println("Starting start_VS1003...");
  mp3.begin();
  mp3.setVolumeSteps(100);
  Serial.println("MP3 Object created...");
  mp3.setVolume(myconfig[0].value);
  Serial.println("start_VS1003 complete");
   
}



// Connect to Wi-Fi
void connect_wifi(){

  for (uint8_t this_network=0; this_network< no_wifi_networks; this_network++)
    wifiMulti.addAP(SSID[this_network], PSK[this_network]);
  
  display.fillScreen(TFT_BLACK);
  display.pushImage(25,65,VENDOR_LOGO_WIDTH,VENDOR_LOGO_HEIGHT, VENDOR_LOGO, TFT_BLACK);
  pin_fade(1,LCD_BL);
  display.loadFont(AgnellaBold30);

  String value_string = "IR7";
  int value_string_width = display.textWidth(value_string,1);
   
  display.setTextColor(TFT_WHITE, TFT_BLACK); // Set the font colour AND the background colour
  display.setCursor(120-value_string_width/2, 35);
  display.println(value_string);

  display.loadFont(NotoSansBold15);

  value_string = "Connecting to wifi ...";
  value_string_width = display.textWidth(value_string,1);
  display.fillRect(0,160,240,16,TFT_BLACK);
  display.setTextColor(TFT_WHITE, TFT_BLACK); 
  display.setCursor(120-value_string_width/2, 160);
  display.println(value_string);

  unsigned long start_time = millis();
  while(1)
  {
      if (wifiMulti.run(connectTimeoutMs) == WL_CONNECTED) {
        String value_string = String(WiFi.SSID());
        int value_string_width = display.textWidth(value_string,1);
        display.fillRect(0,160,240,16,TFT_BLACK);
        display.setTextColor(TFT_WHITE, TFT_BLACK); 
        display.setCursor(120-value_string_width/2, 160);
        display.println(value_string);
        Serial.print("WiFi connected: ");
        Serial.print(WiFi.SSID());
        Serial.print(" ");
        Serial.println(WiFi.RSSI());
        break;
      }
      if ((millis()-start_time)>60000)
        got_to_sleep();
      if (digitalRead(ENC1_BUT)==LOW)
        got_to_sleep();
    }   
  pin_fade(0,LCD_BL);
}

// Start radio stream
void start_stream()
{
  mp3.connecttohost(this_stream_url);
  Serial.println("start_stream complete");
}

// Initialize display
void init_display(){
  display.init();
  display.fillScreen(TFT_BLACK);
  display.setTextColor(TFT_WHITE, TFT_BLACK);
  display.setTextWrap(false, false);
  display.setTextSize(2);
  display.setSwapBytes(true);
}

// Set-up I/O
void init_io()
{
  

  pinMode(VS1053_RST, OUTPUT); 
  pinMode(VS1053_CS,OUTPUT);
  pinMode(VS1053_DCS,OUTPUT);
  digitalWrite(VS1053_DCS,HIGH);
  digitalWrite(VS1053_CS,HIGH);
 
  gpio_hold_dis(VS1053_RST);
  digitalWrite(VS1053_RST,LOW); // Reset MP3 decoder board on boot
  delay(10);
  digitalWrite(VS1053_RST,HIGH); // Enable MP3 decoder

  pinMode(LCD_BL, OUTPUT);
  digitalWrite(LCD_BL,LOW); // Disable LCD backlight for now - will fade in later
  
  gpio_hold_dis(MOSFET_EN);
  pinMode(MOSFET_EN, OUTPUT);
  digitalWrite(MOSFET_EN,HIGH); // Enable amp
  
  analogWriteFrequency(50000);

  

  pinMode(VCC_PIN,INPUT);
}

// Start encoders
void start_rot_encoder(){

  active_config=0;
  encoder1.begin();
  encoder1.setup(readEncoderISR1);
  encoder1.setBoundaries(myconfig[active_config].low_limit, myconfig[active_config].high_limit, false); //minValue, maxValue, circleValues true|false (when max go to min and vice versa)    
  encoder1.setAcceleration(250);
  encoder1.setEncoderValue(myconfig[active_config].value);
}

// Use seperate core to do WIFI & mp3 decode stuff
void Task0code( void * pvParameters ){

  for(;;){
      while (xSemaphoreTake(SPIsem, 0) != pdTRUE) {
        delay(1);
      }; 
      mp3.loop();
      xSemaphoreGive(SPIsem);  
      
    delay(1);
    esp_task_wdt_reset();
  } 
}

// Equalizer
void setTone ()
{
        // toneha       = <0..15>        // Setting treble gain (0 off, 1.5dB steps)
        // tonehf       = <0..15>        // Setting treble frequency lower limit x 1000 Hz
        // tonela       = <0..15>        // Setting bass gain (0 = off, 1dB steps)
        // tonelf       = <0..15>        // Setting bass frequency lower limit x 10 Hz

  uint8_t rtone[4]  = {0,0, myconfig[3].value, 15};
  mp3.setTone(rtone);     
}


// Set Time-Zone
void setTimezone(){
  Serial.printf("  Setting Timezone to %s\n",timezone.c_str());
  setenv("TZ",timezone.c_str(),1);  
  tzset();
}

// Setup NTP and time zone
void init_ntp()
{ 
  sntp_set_time_sync_notification_cb(timeSyncCallback);
  sntp_set_sync_interval(5000);
  sntp_setoperatingmode(SNTP_OPMODE_POLL);
  sntp_setservername(0, ntp_server);
  sntp_init();
  setTimezone(); 
}
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
void loop() {

    yield();
    esp_task_wdt_reset();
    delay(10);
    wifiMulti.run();  
    if (encoder1.encoderChanged())
    {
      last_user_activity=millis();
      showFreeMem();
      uint16_t enc_val = encoder1.readEncoder();
      myconfig[active_config].value=enc_val;
      Serial.println("ENC1 VAL: " + String(enc_val));
      if (active_config==0) mp3.setVolume(enc_val);
      if (active_config==1)
      {
        last_station_change=millis();
        change_station=true;
        String station_string=stationList[enc_val];
        int del_pos = station_string.indexOf('@');
        this_stream_url=station_string.substring(del_pos+1);
        this_stream_name=String(enc_val) + " " + station_string.substring(0,del_pos);
        Serial.println(this_stream_url);
        ScrollTextSprite.loadFont(NotoSansBold15);
        int station_name_len=ScrollTextSprite.textWidth(this_stream_name);
        // This generates a sprite with sation title and song name that we will move over the screen
        ScrollTextSprite.pushImage(0,0,240,16,BACKROUND+240*title_pos);
        ScrollTextSprite.setCursor(128-station_name_len/2, 0);
        ScrollTextSprite.setTextColor(TFT_WHITE); 
        ScrollTextSprite.println(this_stream_name);	
        ScrollTextSprite.pushSprite(0, title_pos+1);
        display.drawSmoothArc(120,120,119,120,0,360,TFT_MY_GRAY,TFT_BLACK,false);
      }
      if (active_config==3)
        setTone();
    

      if (active_config==2)
        draw_alarm();
      
    }

    // New station selected
    if ((change_station)&&((millis()-last_station_change)>2000))
    {
      display_text_pos=260;
      yield();
      esp_task_wdt_reset();
      start_stream();
      change_station=false;
      last_text_move=millis()+3000;

    }

    // Encoder button pressed
    if ((digitalRead(ENC1_BUT)==0))
      {
        bool long_press=false;
        unsigned long press_time=millis();

        // Check for long press
        while (digitalRead(ENC1_BUT)==0)
        {
          unsigned long press_duration=millis()-press_time;
          if (press_duration>1000)
          {
            long_press=true; 
            break;
          }
           delay(1);
        }

        if (long_press)
        {
          Serial.println("Button long press");
          if (active_config==0)
            got_to_sleep();
          if (active_config==2)
          {
            alarm_on=!alarm_on;
            draw_alarm();
          }
        }
        else
        {
          Serial.println("Button short press");
          
          myconfig[active_config].value=encoder1.readEncoder();
          active_config++;
          if (active_config >=num_configs)
            active_config=0;
          draw_menu();
          update_encoder_limits();
        }
      // Wait for button to return to 0
      while (digitalRead(ENC1_BUT)==0)
        delay(1);
      last_user_activity=millis();
    }

    // Timeout on menu selection - revert to default menu item (volume)
    if ((millis()-last_user_activity)>15000)
    {
      active_config=0;
      draw_menu();
      update_encoder_limits();
      last_user_activity=millis();
    }

    // 1 second update loop 
    if ((millis()-last_second_update)>1000UL)
    {
      last_second_update = millis();
      sync_ntp();
      draw_time();
      draw_wifi();
      draw_battery();
        
    }

    // 
    if ((auto_sleep) && (millis()>auto_sleep_timeout))
      got_to_sleep();



    // Move station and song name every 20ms
    if (((millis()-last_text_move)>20)&&(mp3.isRunning()) && !change_station)
    {
      last_text_move=millis();
      if(display_text_pos==260)
        display.pushImage(0,title_pos,240,16,BACKROUND+240*title_pos);
      display_text_pos-=1;

      // End of line - start scrolling text from beginning
      if (display_text_pos < -display_text_len-10)
        display_text_pos=240;

      while (xSemaphoreTake(SPIsem, 0) != pdTRUE) {delay(1);}; // Lock with semaphore to prevent interference with SPI trafic for mp3 decoder
      ScrollTextSprite.pushImage(-display_text_pos,0,240,15,BACKROUND+240*title_pos);
      ScrollTextSprite.setCursor(3, 0);
      ScrollTextSprite.setTextColor(TFT_WHITE);
      ScrollTextSprite.println(display_text);	
      ScrollTextSprite.pushSprite(display_text_pos, title_pos+1);
      display.drawSmoothArc(120,120,119,120,0,360,TFT_MY_GRAY,TFT_BLACK,false);
      xSemaphoreGive(SPIsem);  
      
    }
}


void vs1053_showstation(const char* info) {
   station_text=String(info);    
}

void vs1053_showstreamtitle(const char* info) {

  song_text=String(info);
  display_text=String(myconfig[1].value) + " " + station_text+" xxx " + song_text;
  ScrollTextSprite.loadFont(NotoSansBold15);
  display_text_len=ScrollTextSprite.textWidth(display_text);
  display_text_pos=260;
     
}

void audio_eof_stream(const char* info) {
    Serial.printf("End of stream: %s\n", info);
    start_stream();
}

void vs1053_bitrate(const char *br){               
  Serial.print("BITRATE:      ");
  Serial.println(String(br)+"kBit/s");            
  String bitrate = String(br);

  int value_pos=215;
  display.loadFont(NotoSansBold15);
  String value_string = bitrate.substring(0,bitrate.length()-3)+"kBit/s";
  int value_string_len=display.textWidth(value_string);
  display.setTextColor(TFT_WHITE, TFT_DARKGREY); // Set the font colour AND the background colour
  display.pushImage(0,value_pos,240,16,BACKROUND+240*value_pos);
  display.setCursor(120-value_string_len/2, value_pos);
  display.println(value_string); 
}
